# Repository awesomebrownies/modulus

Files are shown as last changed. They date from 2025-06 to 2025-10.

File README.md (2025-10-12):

# Modulus
Modulus is a continuation of my journey within hack club's YSWS hackpad v2. This board features **reversible** PCB's, saving on cost. It has a **separated thumb cluster** utilizing **ribbon cables** and a column stagger layout allowing for ergonomic hand placement. It also includes motors for **haptic feedback**, allowing main row modifiers to be used easily.

The reasoning behind this creation is I wanted a keyboard with a comfortable thumb cluster. Typically a keyboard of this type costs hundreds of dollars to make (though it doesn't have a trackball). I wanted something custom and fun, but at a much lower budget. One of my previous keyboards used main row modifiers without a notification. This version includes motors for haptic feedback, improving user experience.

A couple of tips to putting this together. For the thumb cluster PCB, solder the bridges on the top side where the microcontroller is mounted for proper functionality. Other than that, you just need to connect the ribbon cable and everything else is standard for setting up any other ergo keyboard.

## Bill of Materials

<table>
  <thead>
    <tr>
      <th>Category</th>
      <th>Item Description</th>
      <th>Vendor</th>
      <th>Price</th>
      <th>Shipping</th>
      <th>Total</th>
      <th>Link</th>
    </tr>
  </thead>
  <tbody>
    <tr>
      <td><strong>Microcontrollers</strong></td>
      <td>2x Orpheus Pico's or Raspberry Pi Picos</td>
      <td>Aliexpress</td>
      <td>$8.00</td>
      <td>Free</td>
      <td><strong>$8.00</strong></td>
      <td><a href="https://vilros.com/products/raspberry-pi-pico">Link</a></td>
    </tr>
    <tr>
      <td><strong>Switches</strong></td>
      <td>45 pcs Rosewood Akko Switches</td>
      <td>Amazon</td>
      <td>$16.99</td>
      <td>Free</td>
      <td><strong>$16.99</strong></td>
      <td><a href="https://www.amazon.com/Akko-Rosewood-Keyboard-Mechanical-Pre-Lubed/dp/B0D7VG2QJH?th=1">Link</a></td>
    </tr>
    <tr>
      <td><strong>Keycaps</strong></td>
      <td>Honey Milk Keycaps (Keycap set)</td>
      <td>Amazon</td>
      <td>$22.00</td>
      <td>Free</td>
      <td><strong>$22.00</strong></td>
      <td><a href="https://www.amazon.com/Keycaps-Minimalist-Compatible-Mechanical-Keyboards/dp/B0948XRKCQ/">Link</a></td>
    </tr>
    <tr>
      <td rowspan="3"><strong>Electronic Components</strong></td>
      <td>Kailh Hotswap Socket</td>
      <td>AliExpress</td>
      <td>$6.42</td>
      <td>Free</td>
      <td rowspan="3"><strong>$14.27</strong></td>
      <td><a href="https://www.aliexpress.us/item/3256803389452947.html">Link</a></td>
    </tr>
    <tr>
      <td>Mini Motor Disc</td>
      <td>Aliexpress</td>
      <td>$3.31</td>
      <td>$3.00</td>
      <td><a href="https://www.aliexpress.us/item/3256806157955199.html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">Link</a></td>
    </tr>
    <tr>
      <td>SOD-123 Diode</td>
      <td>Aliexpress</td>
      <td>$1.54</td>
      <td>Free</td>
      <td><a href="https://www.aliexpress.us/item/2251832693131413.html">Link</a></td>
    </tr>
    <tr>
      <td rowspan="2"><strong>Grant</strong></td>
      <td>2x PCB</td>
      <td>JLCPCB</td>
      <td>$14.26</td>
      <td>$14.14</td>
      <td rowspan="2"><strong>$32.03</strong></td>
      <td>N/A</td>
    </tr>
    <tr>
      <td>Ribbon Cable</td>
      <td>AliExpress</td>
      <td>$1.45</td>
      <td>$1.99</td>
      <td><a href="https://www.aliexpress.us/item/3256807375022913.html">Link</a></td>
    </tr>
  </tbody>
</table>

TOTAL: ~$89 (Depending on choice item selection)

Screenshot from 2025-06-06 13-33-11
Screenshot from 2025-03-23 22-03-59

Screenshot from 2025-06-06 13-00-55
Screenshot from 2025-06-06 13-01-10

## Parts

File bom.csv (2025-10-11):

Category | Item Description | Vendor | Price | Shipping | Total | Link
Microcontrollers | 2x Orpheus Pico's or Raspberry Pi Picos | Vilros | $8.00 | Free | $8.00 | https://vilros.com/products/raspberry-pi-pico
Switches | 45 pcs Rosewood Akko Switches | Amazon | $16.99 | Free | $16.99 | https://www.amazon.com/Akko-Rosewood-Keyboard-Mechanical-Pre-Lubed/dp/B0D7VG2QJH?th=1
Keycaps | Honey Milk Keycaps (Keycap set) | Amazon | $22.00 | Free | $22.00 | https://www.amazon.com/Keycaps-Minimalist-Compatible-Mechanical-Keyboards/dp/B0948XRKCQ/
Electronic Components | Kailh Hotswap Socket | AliExpress | $6.42 | Free | $20.24 | https://www.aliexpress.us/item/3256803389452947.html
Electronic Components | Mini Motor Disc | Aliexpress | $3.11 | $3.00 |  | https://www.aliexpress.com/p/tesla-landing/index.html?scenario=c_ppc_item_bridge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
Electronic Components | SOD-123 Diode | Aliexpress | $1.54 | Free |  | https://www.aliexpress.us/item/2251832693131413.html
Grant | 2x PCB | JLCPCB | $14.26 | $14.14 | $32.03 | N/A
Grant | Ribbon Cable | AliExpress | $1.45 | $1.99 |  | $https://www.aliexpress.us/item/3256807375022913.html

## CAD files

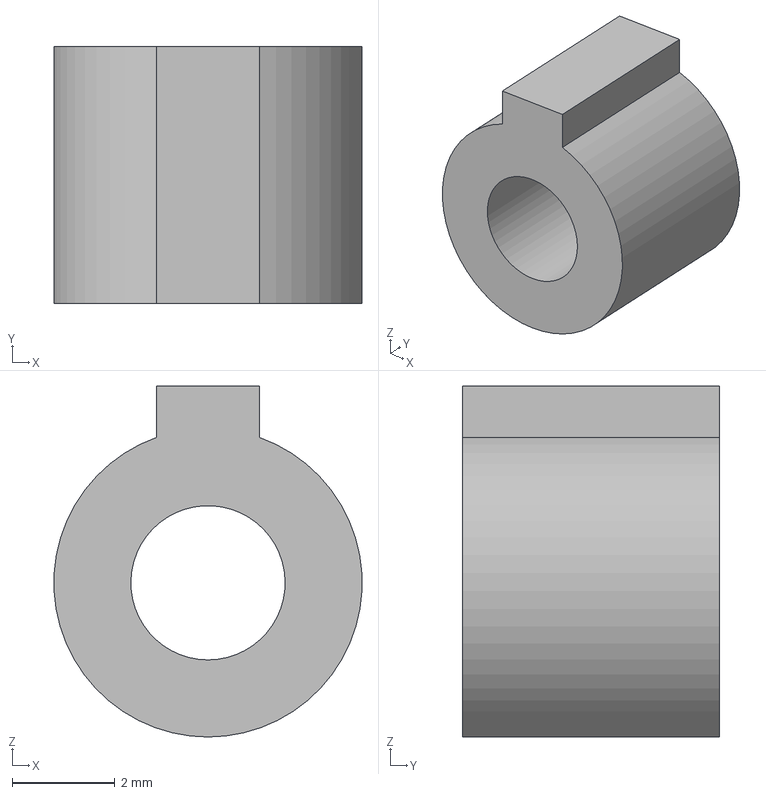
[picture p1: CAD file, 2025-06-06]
CAD/Main Body Mount.step
5.99 x 5.00 x 6.83 mm

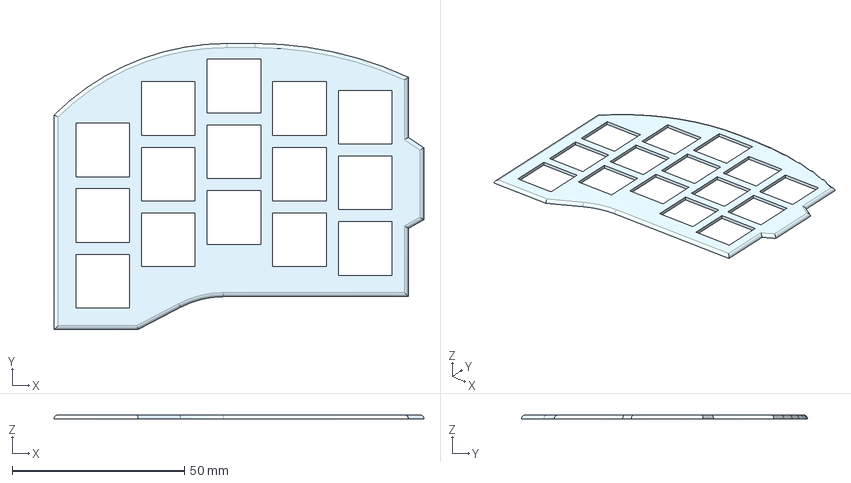
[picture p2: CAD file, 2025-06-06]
CAD/Main Body Cover.step
107.3 x 83.0 x 1.20 mm

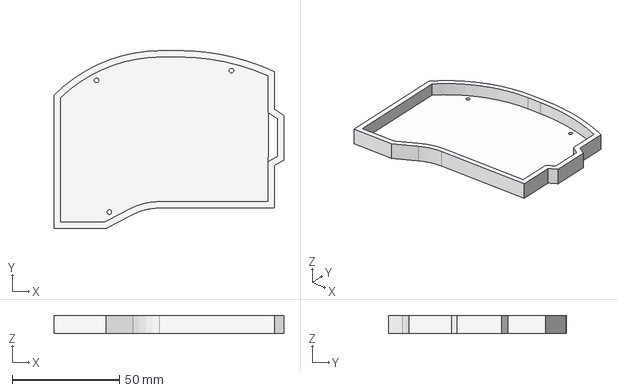
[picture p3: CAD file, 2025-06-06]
CAD/Main Body.step
107.3 x 83.0 x 8.60 mm

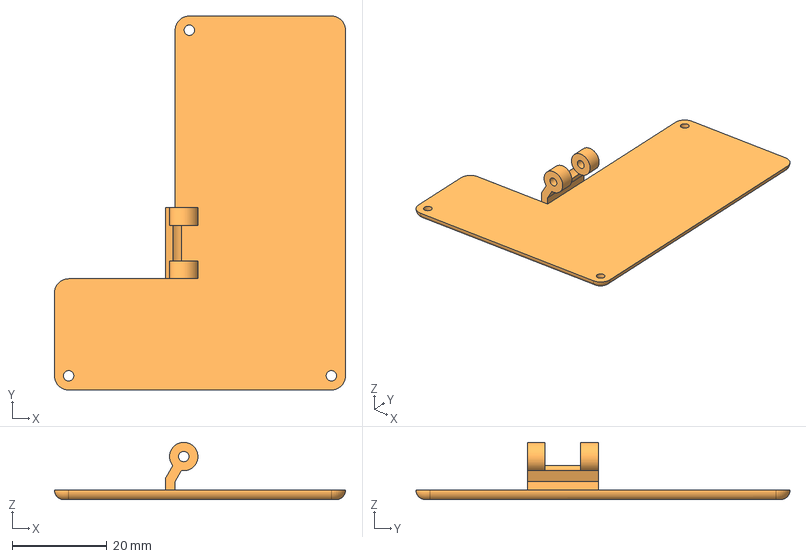
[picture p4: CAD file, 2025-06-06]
CAD/Thumb Cluster.step
61.5 x 79.0 x 12.1 mm

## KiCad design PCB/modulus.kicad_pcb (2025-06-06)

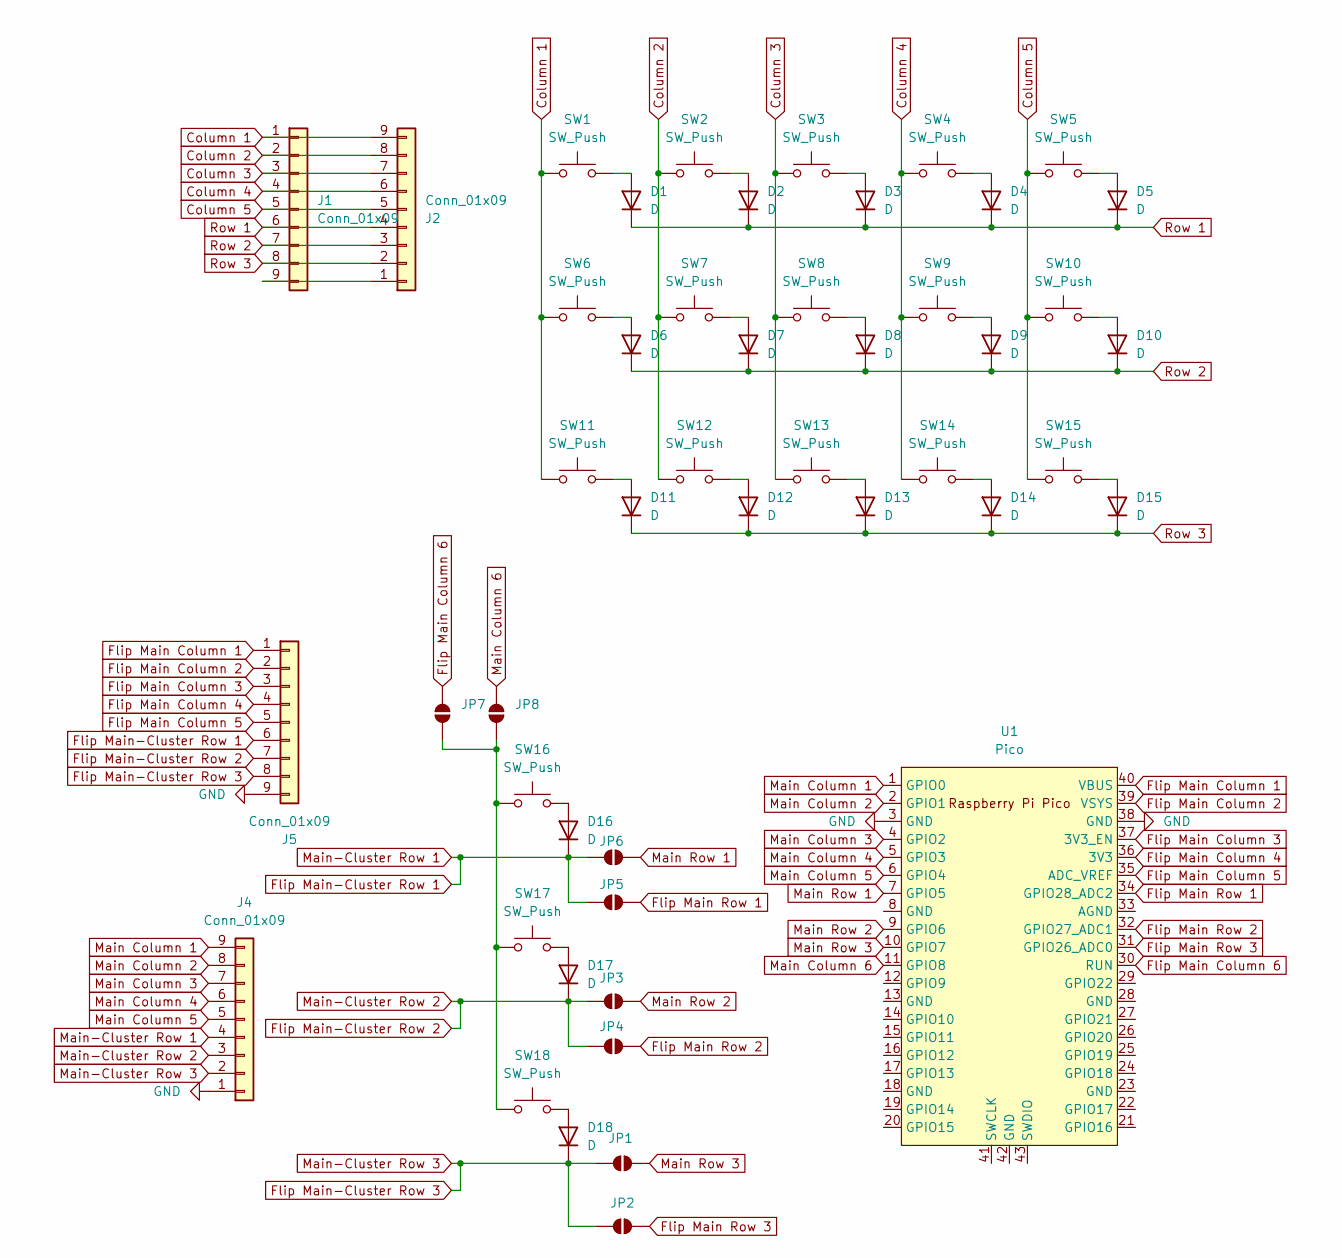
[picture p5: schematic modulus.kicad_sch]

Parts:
D1, D2, D3, D4, D5, D6, D7, D8, D9, D10, D11, D12, D13, D14, D15, D16, D17, D18: D; D3_SMD
J1, J2, J4, J5: Conn_01x09; Molex_200528-0090_1x09-1MP_P1.00mm_Horizontal
JP1, JP2, JP3, JP4, JP5, JP6, JP7, JP8: SolderJumper_2_Open; SolderJumper-2_P1.3mm_Open_TrianglePad1.0x1.5mm
SW1, SW2, SW3, SW4, SW5, SW6, SW7, SW8, SW9, SW10, SW11, SW12, SW13, SW14, SW15, SW16, SW17, SW18: SW_Push; Kailh_socket_MX_reversible
U1: Pico; RPi_Pico_SMD_TH

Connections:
Column 1: J1.1, J2.9, SW1.1, SW6.1, SW11.1
Column 2: J1.2, J2.8, SW2.1, SW7.1, SW12.1
Column 3: J1.3, J2.7, SW3.1, SW8.1, SW13.1
Column 4: J1.4, J2.6, SW4.1, SW9.1, SW14.1
Column 5: J1.5, J2.5, SW5.1, SW10.1, SW15.1
Flip Main Column 1: J5.1, U1.40 (VBUS)
Flip Main Column 2: J5.2, U1.39 (VSYS)
Flip Main Column 3: J5.3, U1.37 (3V3_EN)
Flip Main Column 4: J5.4, U1.36 (3V3)
Flip Main Column 5: J5.5, U1.35 (ADC_VREF)
Flip Main Column 6: JP7.2 (B), U1.30 (RUN)
Flip Main Row 1: JP5.2 (B), U1.34 (GPIO28_ADC2)
Flip Main Row 2: JP4.2 (B), U1.32 (GPIO27_ADC1)
Flip Main Row 3: JP2.2 (B), U1.31 (GPIO26_ADC0)
Flip Main-Cluster Row 1: D16.1 (K), J4.4, J5.6, JP5.1 (A), JP6.1 (A)
Flip Main-Cluster Row 2: D17.1 (K), J4.3, J5.7, JP3.1 (A), JP4.1 (A)
Flip Main-Cluster Row 3: D18.1 (K), J4.2, J5.8, JP1.1 (A), JP2.1 (A)
GND: J4.1, J5.9, U1.3 (GND), U1.38 (GND)
Main Column 1: J4.9, U1.1 (GPIO0)
Main Column 2: J4.8, U1.2 (GPIO1)
Main Column 3: J4.7, U1.4 (GPIO2)
Main Column 4: J4.6, U1.5 (GPIO3)
Main Column 5: J4.5, U1.6 (GPIO4)
Main Column 6: JP8.2 (B), U1.11 (GPIO8)
Main Row 1: JP6.2 (B), U1.7 (GPIO5)
Main Row 2: JP3.2 (B), U1.9 (GPIO6)
Main Row 3: JP1.2 (B), U1.10 (GPIO7)
unnamed: D1.2 (A), SW1.2
unnamed: D2.2 (A), SW2.2
unnamed: D3.2 (A), SW3.2
unnamed: D4.2 (A), SW4.2
unnamed: D5.2 (A), SW5.2
unnamed: D6.2 (A), SW6.2
unnamed: D7.2 (A), SW7.2
unnamed: D8.2 (A), SW8.2
unnamed: D9.2 (A), SW9.2
unnamed: D10.2 (A), SW10.2
unnamed: D11.2 (A), SW11.2
unnamed: D12.2 (A), SW12.2
unnamed: D13.2 (A), SW13.2
unnamed: D14.2 (A), SW14.2
unnamed: D15.2 (A), SW15.2
unnamed: D16.2 (A), SW16.2
unnamed: D17.2 (A), SW17.2
unnamed: D18.2 (A), SW18.2
unnamed: J1.9, J2.1
unnamed: JP7.1 (A), JP8.1 (A), SW16.1, SW17.1, SW18.1
Row 1: D1.1 (K), D2.1 (K), D3.1 (K), D4.1 (K), D5.1 (K), J1.6, J2.4
Row 2: D6.1 (K), D7.1 (K), D8.1 (K), D9.1 (K), D10.1 (K), J1.7, J2.3
Row 3: D11.1 (K), D12.1 (K), D13.1 (K), D14.1 (K), D15.1 (K), J1.8, J2.2

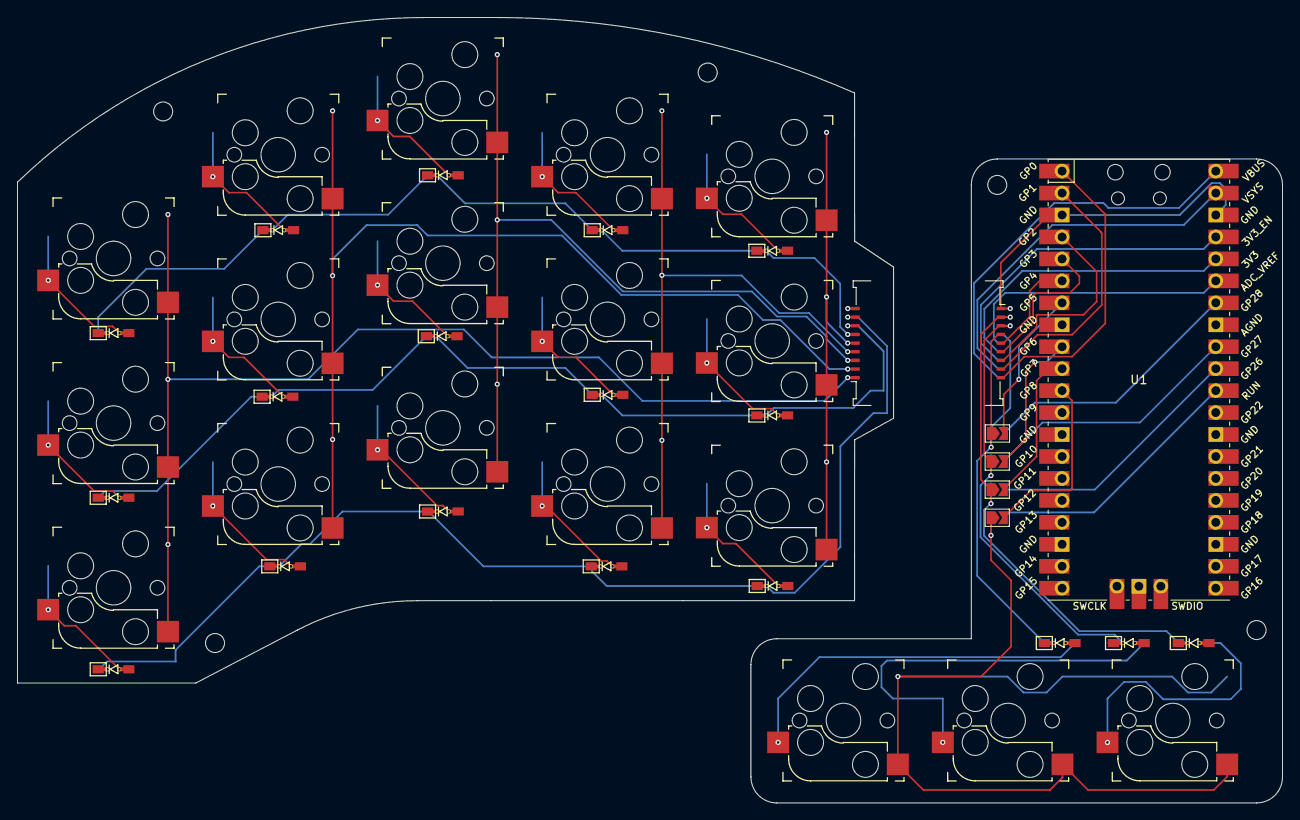
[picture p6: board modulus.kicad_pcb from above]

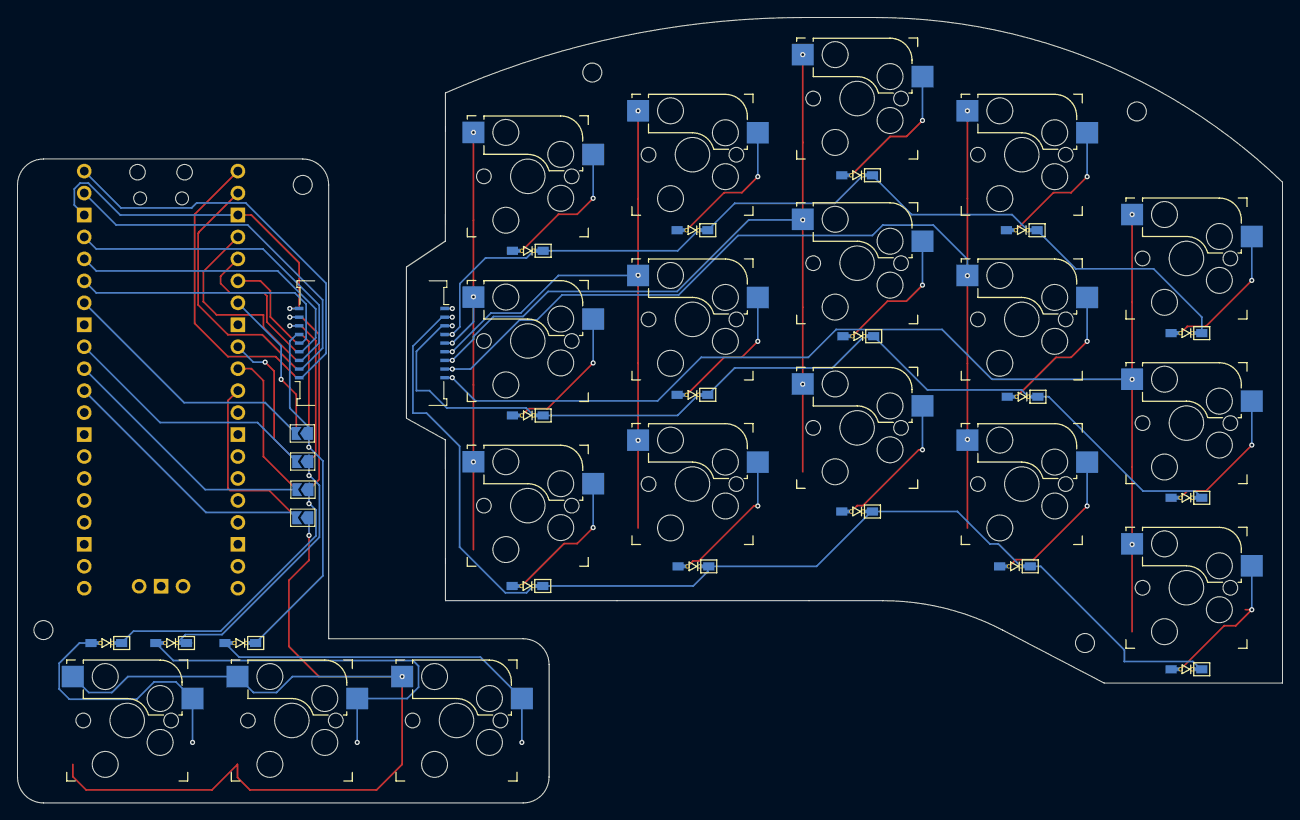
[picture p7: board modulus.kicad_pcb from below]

Board: 2 copper layers, 146.3 x 90.9 mm, 49 parts (6 on the bottom side), 50 nets.

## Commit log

2025-03-15 Add modulus files
    [Grove - Vision AI Module V2.kicad_pcb, Grove - Vision AI Module V2.kicad_sch, Grove_Vision_AI_V2_BOM.xlsx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]
2025-03-24 Remove libraries
    [Grove - Vision AI Module V2.kicad_pcb, Grove - Vision AI Module V2.kicad_sch, Grove_Vision_AI_V2_BOM.xlsx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]
2025-03-24 Reformat structure
    [modulus.kicad_pcb, modulus.kicad_sch]
2025-03-24 Add latest PCB version
    [modulus.kicad_pcb, modulus.kicad_sch]
2025-03-24 Relocate files
    [modulus.kicad_pcb, modulus.kicad_sch]
2025-06-05 Update from M3 to M2 holes
    [modulus.kicad_pcb]
2025-06-06 Add 3d print files
    [Main Body Cover.step, Main Body Mount.step, Main Body.step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]
2025-06-06 Minimize thumb cluster
    [modulus.kicad_pcb]
